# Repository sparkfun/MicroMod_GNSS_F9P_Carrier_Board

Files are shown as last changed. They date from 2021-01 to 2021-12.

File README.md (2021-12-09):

SparkFun MicroMod GNSS Carrier Board (ZED-F9P)
========================================

SparkFun MicroMod GNSS Carrier Board (ZED-F9P) (https://www.sparkfun.com/products/17722)

[*SparkFun MicroMod GNSS Carrier Board (ZED-F9P) (GPS-17722)*](https://www.sparkfun.com/products/17722)

With GNSS you are able to know where you are, where you're going, and how to get there anywhere on Earth within 30 seconds. This means the higher the accuracy the better! GNSS Real Time Kinematics (RTK) has mastered dialing in the accuracy of their GNSS modules to just millimeters, and that's why we had to put it on this board! With the flexibility of the MicroMod's M.2 connector, you can easily test and swap out different MicroMod processor boards for your application. Simply match up the key on your board's beveled edge connector to the key on the M.2 connector and secure the boards with a screw.

The SparkFun MicroMod GNSS Carrier Board raises the bar for high-precision GPS and is in a line of powerful RTK boards featuring the ZED-F9P module from u-blox. The ZED-F9P is a top-of-the-line module for high accuracy GNSS and GPS location solutions including RTK that is capable of 10mm, three-dimensional accuracy. With this board, you will be able to know where your (or any object's) X, Y, and Z location is within roughly the width of your fingernail! The ZED-F9P is unique in that it is capable of both rover and base station operations. Utilizing the M.2 and Qwiic connectors, no soldering is required to connect it to the rest of your system. However, we still broke out 0.1"-spaced pins in case you prefer to use a breadboard to attach additional peripherals.

The board includes two USB-C connectors for power and programming. Two buttons for reset and boot are also populated on the board. A 2A resettable fuse and 3.3V/1A voltage regulator are built-in to the board for power. We've even added a convenient jumper for advanced users looking to bypass the fuse and another to measure the current consumption for low power testing. Five status LEDs are available for power, 3.3V, PPS, RTK, and geofencing. These can also be disabled via the jumper pads. One SMA connector is included for a secure connection to an antenna. For those that need a secure connection to the PPS pin, the SMA connector footprint is included in the design so that you can manually solder it to the board for your application. Finally, one Qwiic connector is populated on the board to easily add Qwiic enabled I<sup>2</sup>C devices to your projects!

We've even included a rechargeable backup battery to keep the latest module configuration and satellite data available for up to two weeks. This battery helps 'warm-start' the module, decreasing the time-to-first-fix dramatically. This module features a survey-in mode allowing the module to become a base station and produce RTCM 3.x correction data.

The number of configuration options of the ZED-F9P is incredible! Geofencing, variable I<sup>2</sup>C address, variable update rates, even the high precision RTK solution can be increased to 20Hz. The MicroMod GNSS carrier board even has five communications ports, four of which are all active simultaneously: USB-C (which enumerates as a COM port), UART1 (with 3.3V TTL), UART2 for RTCM reception (with 3.3V TTL), I<sup>2</sup>C (via the one Qwiic connector or broken out pins), and SPI.

We've also written an extensive [Arduino library for u-blox modules](https://github.com/sparkfun/SparkFun_u-blox_GNSS_Arduino_Library) to make reading and controlling the MicroMod GNSS carrier board over the MicroMod's I<sup>2</sup>C bus is easy. Leave NMEA behind! Start using a much lighter weight binary interface and give your microcontroller (and its one serial port) a break. The SparkFun Arduino library shows how to read latitude, longitude, even heading and speed over I<sup>2</sup>C without the need for constant serial polling.

Repository Contents
-------------------

* **/Hardware** - Eagle design files (.brd, .sch)
* **/Production** - Production panel files (.brd)

Documentation
--------------
* **[Library](https://github.com/sparkfun/SparkFun_u-blox_GNSS_Arduino_Library)** - Arduino library for the u-blox modules (e.g. ZED-F9P)
* **[Hookup Guide](https://learn.sparkfun.com/tutorials/2187)** - Basic hookup guide for the ZED-F9P Carrier Board

Product Versions
----------------
* [GPS-17722](https://www.sparkfun.com/products/17722) 

Version History
---------------
* v1.0 - initial release

License Information
-------------------

This product is _**open source**_! 

Please review the LICENSE.md file for license information. 

If you have any questions or concerns on licensing, please contact technical support on our [SparkFun forums](https://forum.sparkfun.com/viewforum.php?f=152).

Distributed as-is; no warranty is given.

- Your friends at SparkFun.

_<COLLABORATION CREDIT>_

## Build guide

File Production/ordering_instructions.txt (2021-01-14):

panel size, 149x147mm
PCB thickness, 1.6mm
number of layers, 2
soldermask color, Red
silkscreen color, White
oz copper, 1oz
finish, HASL lead free
stencils, top
pcs per panel, 4
min trace width, 0.1524mm / 0.0060in
min drill size, 0.3048mm / 0.0120in

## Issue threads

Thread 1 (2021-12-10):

Voltage divider jumper

adamgarbo, 2021-12-10:
Hi @edspark,

Another exciting design. I assume when I raised the issue regarding the voltage divider jumper with you last that this product was likely already being manufactured?

I know I sound like a broken record by now, but with a couple of small improvements, the power efficiency of the MicroMod ecosystem of products could be vastly improved. I'll keep pushing low power and hopefully one day we'll get there!

Cheers,
Adam

adamgarbo, 2022-03-10:
Power efficiency issues with the MicroMod ecosystem is a known issue and will hopefully be addressed in future MicroMod products.

Closed 2022-03-10.

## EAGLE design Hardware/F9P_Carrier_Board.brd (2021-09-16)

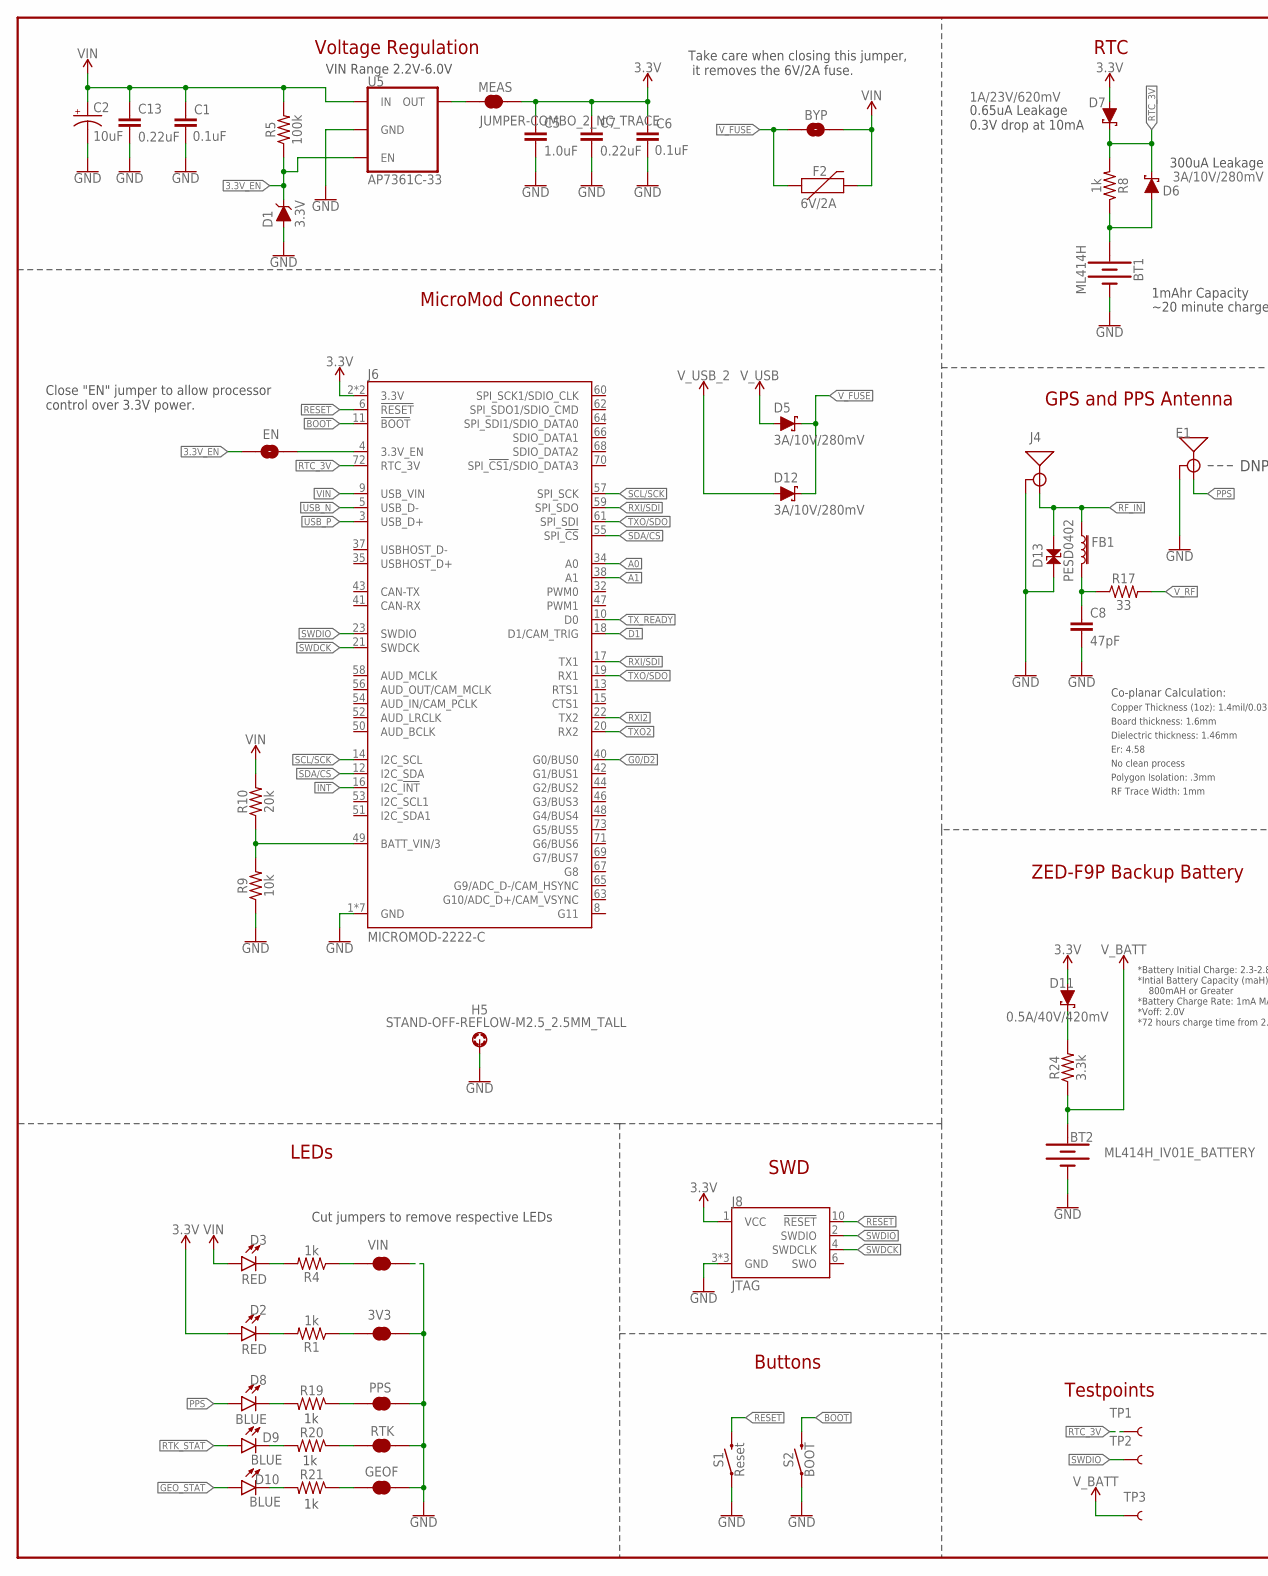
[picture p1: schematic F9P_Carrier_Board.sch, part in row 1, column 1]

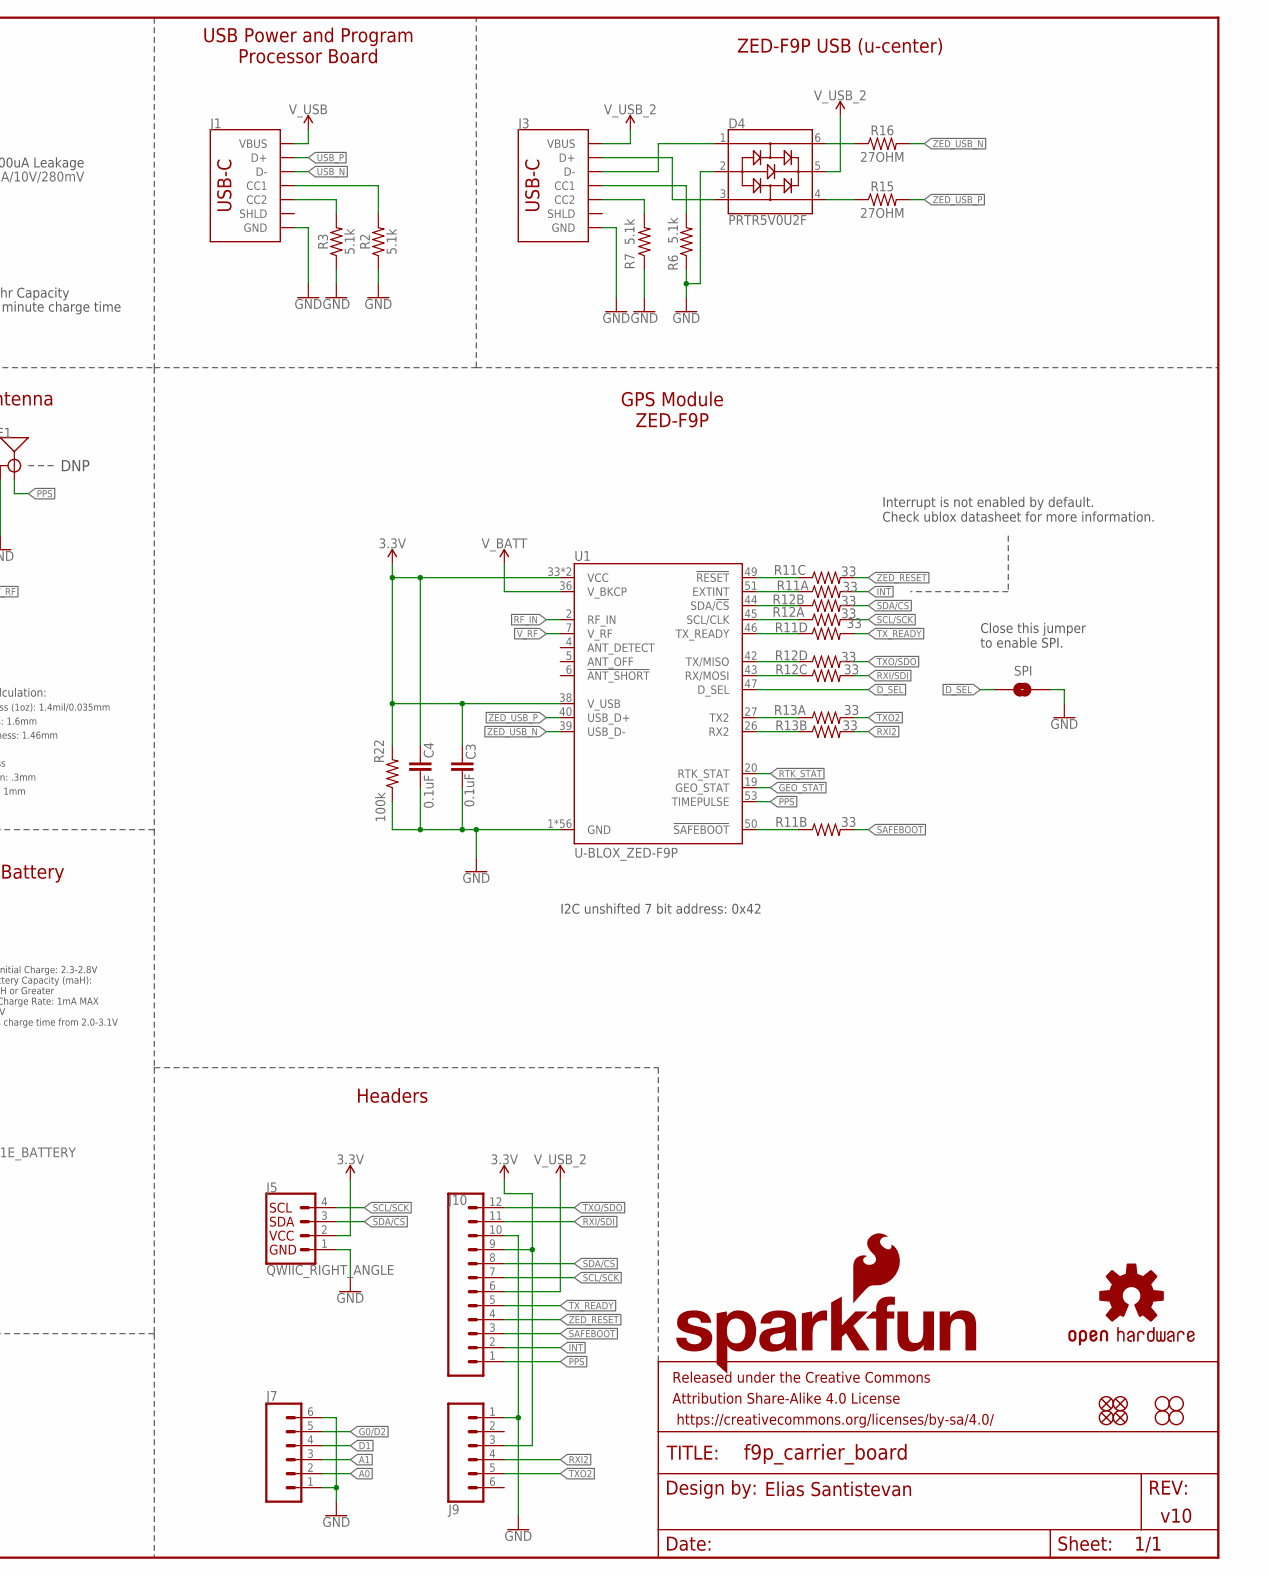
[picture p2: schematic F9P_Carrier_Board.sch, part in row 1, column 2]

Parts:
3V3: JUMPER-SMT_2_NC_TRACE_SILK; SMT-JUMPER_2_NC_TRACE_SILK
BT1: ML414H; ML414H_IV01E
BT2: ML414H_IV01E_BATTERY; ML414H_IV01E
BYP: JUMPER-SMT_2_NO_SILK; SMT-JUMPER_2_NO_SILK
C1, C3, C4, C6: 0.1uF; 0603
C2: 10uF; EIA3216
C5: 1.0uF; 0603
C7, C13: 0.22uF; 0603
C8: 47pF; 0603
D1: 3.3V; SOD-323
D2, D3: RED; LED-0603
D4: PRTR5V0U2F; SOT886
D5, D6, D12: 3A/10V/280mV; SOD-323
D7: 1A/23V/620mV; SOD-323
D8, D9, D10: BLUE; LED-0603
D11: 0.5A/40V/420mV; SOD-323
D13: PESD0402; 0402
E1: ANTENNA-SMA-GROUNDEDEDGE_SMA; SMA-EDGE
EN: JUMPER-SMT_2_NO_SILK; SMT-JUMPER_2_NO_SILK
F2: 6V/2A; 1210
FB1: FERRITE_BEAD-120_OHM-0402T; 0402-TIGHT
FD1, FD2, FD3, FD4: FIDUCIALUFIDUCIAL; FIDUCIAL-MICRO
FRAME1: FRAME-LEDGER; CREATIVE_COMMONS
GEOF: JUMPER-SMT_2_NC_TRACE_SILK; SMT-JUMPER_2_NC_TRACE_SILK
H1, H2, H3, H4: STAND-OFFTIGHT; STAND-OFF-TIGHT
H5: STAND-OFF-REFLOW-M2.5_2.5MM_TALL; STAND-OFF-REFLOW-M2.5
J1, J3: USB_C_2-LAYER_PADS; USB-C-16P-2LAYER-PADS
J4: U.FL; SMA-EDGE
J5: QWIIC_RIGHT_ANGLE; JST04_1MM_RA
J6: MICROMOD-2222-C; M.2-CONNECTOR-E
J7, J9: CONN_06NO_SILK_NO_POP; 1X06_NO_SILK
J8: JTAG; 2X5-PTH-1.27MM
J10: CONN_12NO_SILK; 1X12_NO_SILK
LOGO1: SFE_LOGO_NAME_FLAME.3_INCH; SFE_LOGO_NAME_FLAME_.3
LOGO3: OSHW-LOGOMINI; OSHW-LOGO-MINI
MEAS: JUMPER-COMBO_2_NC_TRACE; COMBO-JUMPER_2_NC_TRACE
PPS: JUMPER-SMT_2_NC_TRACE_SILK; SMT-JUMPER_2_NC_TRACE_SILK
R1, R4, R8, R19, R20, R21: 1k; 0603
R2, R3, R6, R7: 5.1k; 0603
R5, R22: 100k; 0603
R9: 10k; 0603
R10: 20k; 0603
R11, R12, R13: 33; 1206_RA
R15, R16: 27OHM; 0402-TIGHT
R17: 33; 0603
R24: 3.3k; 0603
RTK: JUMPER-SMT_2_NC_TRACE_SILK; SMT-JUMPER_2_NC_TRACE_SILK
S1: Reset; TACTILE_SWITCH_SMD_5.2MM
S2: BOOT; TACTILE_SWITCH_SMD_5.2MM
SPI: JUMPER-SMT_2_NO_SILK; SMT-JUMPER_2_NO_SILK
TP1, TP2, TP3: TEST-POINT3X5; PAD.03X.05
U1: U-BLOX_ZED-F9P; ZED-F9P
U5: AP7361C-33; UDFN-8
VIN: JUMPER-SMT_2_NC_TRACE_SILK; SMT-JUMPER_2_NC_TRACE_SILK

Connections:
3.3V: C3.1, C4.1, C5.1, C6.1, C7.1, D2.A, D7.A, D11.A, J5.2, J6.2 (3.3V), J6.74 (3.3V), J8.1 (VCC), J9.3, J10.9, MEAS.2, MEAS.4 (2), R22.2, U1.33 (VCC), U1.34 (VCC), U1.38 (V_USB)
3.3V_EN: D1.C, EN.1, R5.1, U5.5 (EN)
!BOOT!: J6.11 (!BOOT!), S2.3 (2), S2.4 (2)
!RESET!: J6.6 (!RESET!), J8.10 (!RESET), S1.3 (2), S1.4 (2)
!SAFEBOOT!: J10.3, R11.P7 (2)
!ZED_RESET!: J10.4, R11.P6 (2)
A0: J6.34 (A0), J7.2
A1: J6.38 (A1), J7.3
D1: J6.18 (D1/CAM_TRIG), J7.4
D_SEL: SPI.1, U1.47 (D_SEL)
G0/D2: J6.40 (G0/BUS0), J7.5
GEO_STAT: D10.A, U1.19 (GEO_STAT)
GND: 3V3.2, BT1.-, BT2.-, C1.2, C2.-, C3.2, C4.2, C5.2, C6.2, C7.2, C8.2, C13.2, D1.A, D4.2, D13.1, E1.GND@0 (GND), E1.GND@1 (GND), E1.GND@2 (GND), E1.GND@3 (GND), GEOF.1, H5.1, J1.GND, J1.GND2 (GND), J3.GND, J3.GND2 (GND), J4.GND@0 (GND), J4.GND@1 (GND), J4.GND@2 (GND), J4.GND@3 (GND), J5.1, J6.1 (GND), J6.7 (GND), J6.33 (GND), J6.36 (GND), J6.39 (GND), J6.45 (GND), J6.75 (GND), J7.1, J7.6, J8.3 (GND), J8.5 (GND), J8.9 (GND), J9.1, J10.10, PPS.1, R2.1, R3.1, R6.1, R7.1, R9.1, R22.1, RTK.1, S1.1, S1.2 (1), S2.1, S2.2 (1), SPI.2, U1.1 (GND), U1.3 (GND), U1.12 (GND), U1.14 (GND), U1.32 (GND), U1.37 (GND), U1.41 (GND), U1.48 (GND), U1.55 (GND), U1.56 (GND), U1.57 (GND), U1.58 (GND), U1.59 (GND), U1.60 (GND), U1.61 (GND), U1.62 (GND), U1.63 (GND), U1.64 (GND), U1.65 (GND), U1.66 (GND), U1.67 (GND), U1.68 (GND), U1.69 (GND), U1.70 (GND), U1.71 (GND), U1.72 (GND), U1.73 (GND), U1.74 (GND), U1.75 (GND), U1.76 (GND), U1.77 (GND), U1.78 (GND), U1.79 (GND), U1.80 (GND), U1.81 (GND), U1.82 (GND), U1.83 (GND), U1.84 (GND), U1.85 (GND), U1.86 (GND), U1.87 (GND), U1.88 (GND), U1.89 (GND), U1.90 (GND), U1.91 (GND), U1.92 (GND), U1.93 (GND), U1.94 (GND), U1.95 (GND), U1.96 (GND), U1.97 (GND), U1.98 (GND), U1.99 (GND), U1.100 (GND), U1.101 (GND), U1.102 (GND), U5.4 (GND), U5.EP (GND), VIN.2
INT: J6.16 (I2C_!INT!), J10.2, R11.P8 (2)
unnamed: D2.C, R1.2
unnamed: R4.1, VIN.1
unnamed: 3V3.1, R1.1
unnamed: D3.C, R4.2
unnamed: EN.2, J6.4 (3.3V_EN)
unnamed: J3.A5 (CC1), R6.2
unnamed: J3.B5 (CC2), R7.2
unnamed: R20.1, RTK.2
unnamed: D4.6, R16.1
unnamed: J1.A5 (CC1), R2.2
unnamed: J1.B5 (CC2), R3.2
unnamed: D4.3, J3.A6 (D+), J3.B6 (D+)
unnamed: D4.1, J3.A7 (D-), J3.B7 (D-)
unnamed: BT1.+, D6.A, R8.1
unnamed: R11.P1 (1), U1.51 (EXTINT)
unnamed: R11.P2 (1), U1.50 (!SAFEBOOT!)
unnamed: D4.4, R15.1
unnamed: C8.1, FB1.2, R17.1
unnamed: R11.P3 (1), U1.49 (!RESET!)
unnamed: R11.P4 (1), U1.46 (TX_READY)
unnamed: R12.P1 (1), U1.45 (SCL/CLK)
unnamed: R12.P2 (1), U1.44 (SDA/!CS!)
unnamed: R12.P3 (1), U1.43 (RX/MOSI)
unnamed: R12.P4 (1), U1.42 (TX/MISO)
unnamed: R13.P1 (1), U1.27 (TX2)
unnamed: R13.P2 (1), U1.26 (RX2)
unnamed: PPS.2, R19.1
unnamed: D8.C, R19.2
unnamed: D9.C, R20.2
unnamed: D11.C, R24.2
unnamed: GEOF.2, R21.1
unnamed: D10.C, R21.2
OUT_MEAS: MEAS.1, MEAS.3 (1), U5.1 (OUT)
PPS: D8.A, E1.SIG (SIGNAL), J10.1, U1.53 (TIMEPULSE)
RF_IN: D13.2, FB1.1, J4.SIG (SIGNAL), U1.2 (RF_IN)
RTC_3V: D6.C, D7.C, J6.72 (RTC_3V), R8.2, TP1.1
RTK_STAT: D9.A, U1.20 (RTK_STAT)
RXI2: J6.22 (TX2), J9.4, R13.P7 (2)
RXI/SDI: J6.17 (TX1), J6.59 (SPI_SDO), J10.11, R12.P6 (2)
SCL/SCK: J5.4, J6.14 (I2C_SCL), J6.57 (SPI_SCK), J10.7, R12.P8 (2)
SDA/!CS!: J5.3, J6.12 (I2C_SDA), J6.55 (SPI_!CS!), J10.8, R12.P7 (2)
SWDCK: J6.21 (SWDCK), J8.4 (SWDCLK)
SWDIO: J6.23 (SWDIO), J8.2 (SWDIO), TP2.1
TXO2: J6.20 (RX2), J9.5, R13.P8 (2)
TXO/SDO: J6.19 (RX1), J6.61 (SPI_SDI), J10.12, R12.P5 (2)
TX_READY: J6.10 (D0), J10.5, R11.P5 (2)
USB_N: J1.A7 (D-), J1.B7 (D-), J6.5 (USB_D-)
USB_P: J1.A6 (D+), J1.B6 (D+), J6.3 (USB_D+)
VIN: BYP.2, C1.1, C2.+, C13.1, D3.A, F2.2, J6.9 (USB_VIN), R5.2, R10.2, U5.8 (IN)
VIN/3: J6.49 (BATT_VIN/3), R9.2, R10.1
V_BATT: BT2.+, R24.1, TP3.1, U1.36 (V_BKCP)
V_FUSE: BYP.1, D5.C, D12.C, F2.1
V_RF: R17.2, U1.7 (V_RF)
V_USB: D5.A, J1.VBUS1 (VBUS), J1.VBUS2 (VBUS)
V_USB_2: D4.5, D12.A, J3.VBUS1 (VBUS), J3.VBUS2 (VBUS), J10.6
ZED_USB_N: R16.2, U1.39 (USB_D-)
ZED_USB_P: R15.2, U1.40 (USB_D+)

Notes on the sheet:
300uA Leakage
0.65uA Leakage 0.3V drop at 10mA
~20 minute charge time
1mAhr Capacity
Take care when closing this jumper, it removes the 6V/2A fuse.
RTC
Voltage Regulation
MicroMod Connector
Elias Santistevan
LEDs
Buttons
VIN Range 2.2V-6.0V
Testpoints
*Battery Initial Charge: 2.3-2.8V *Intial Battery Capacity (maH): 800mAH or Greater *Battery Charge Rate: 1mA MAX *Voff: 2.0V *72 hours charge time from 2.0-3.1V
ZED-F9P Backup Battery
Headers
ZED-F9P USB (u-center)
USB Power and Program Processor Board
v10
GPS and PPS Antenna
GPS Module ZED-F9P
SWD
Board thickness: 1.6mm
Er: 4.58
Copper Thickness (1oz): 1.4mil/0.035mm
RF Trace Width: 1mm
Polygon Isolation: .3mm
No clean process
Dielectric thickness: 1.46mm
Co-planar Calculation:
DNP
Close this jumper to enable SPI.
Cut jumpers to remove respective LEDs
Close "EN" jumper to allow processor control over 3.3V power.
Interrupt is not enabled by default. Check ublox datasheet for more information.
I2C unshifted 7 bit address: 0x42

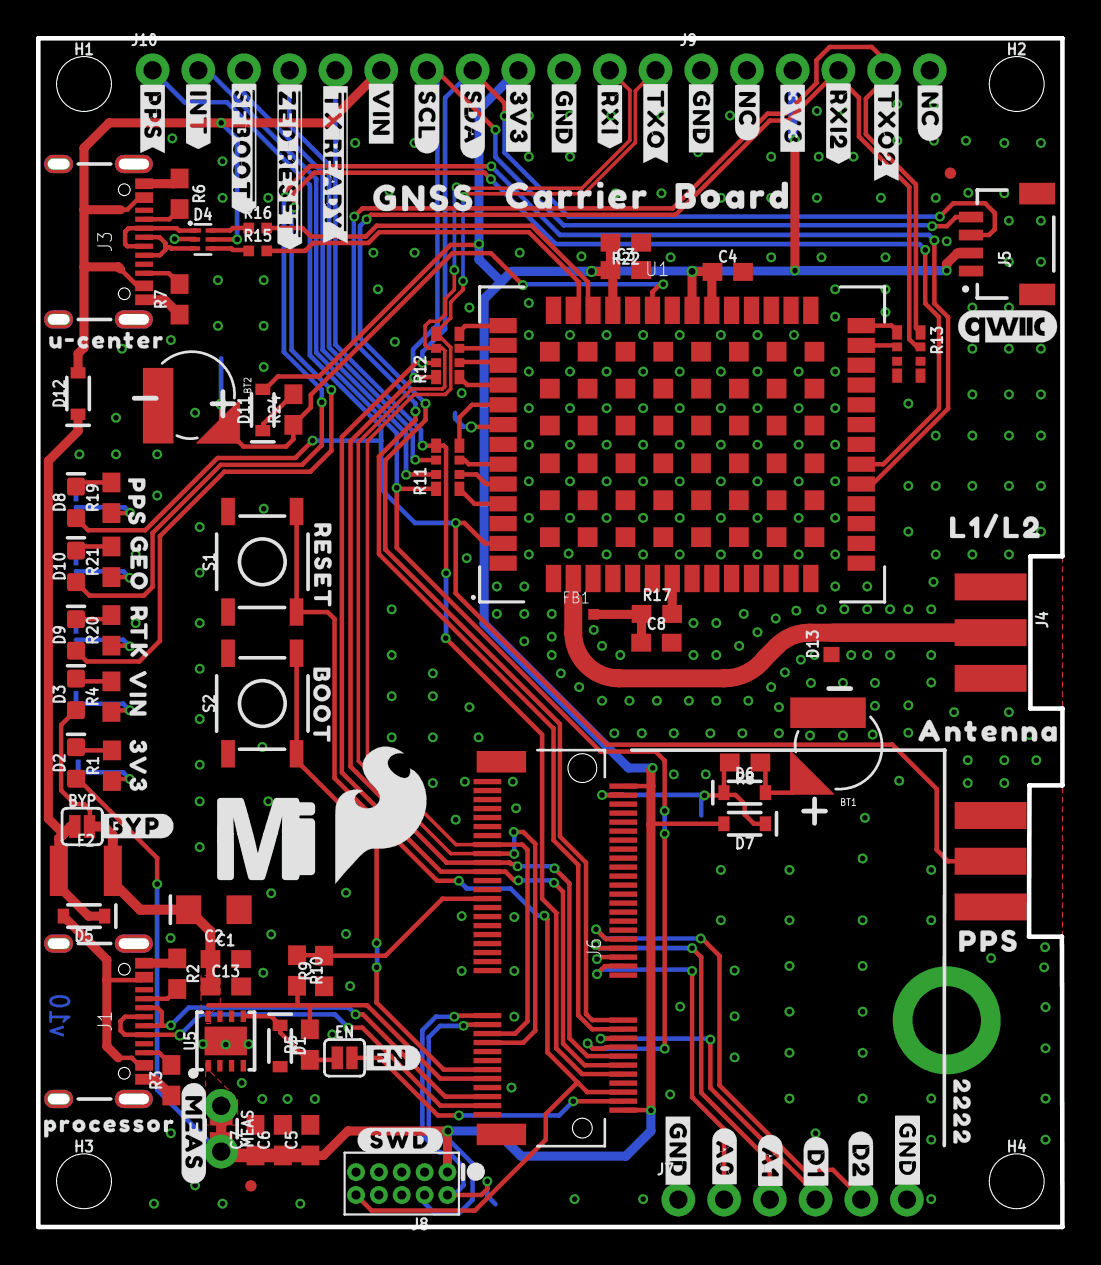
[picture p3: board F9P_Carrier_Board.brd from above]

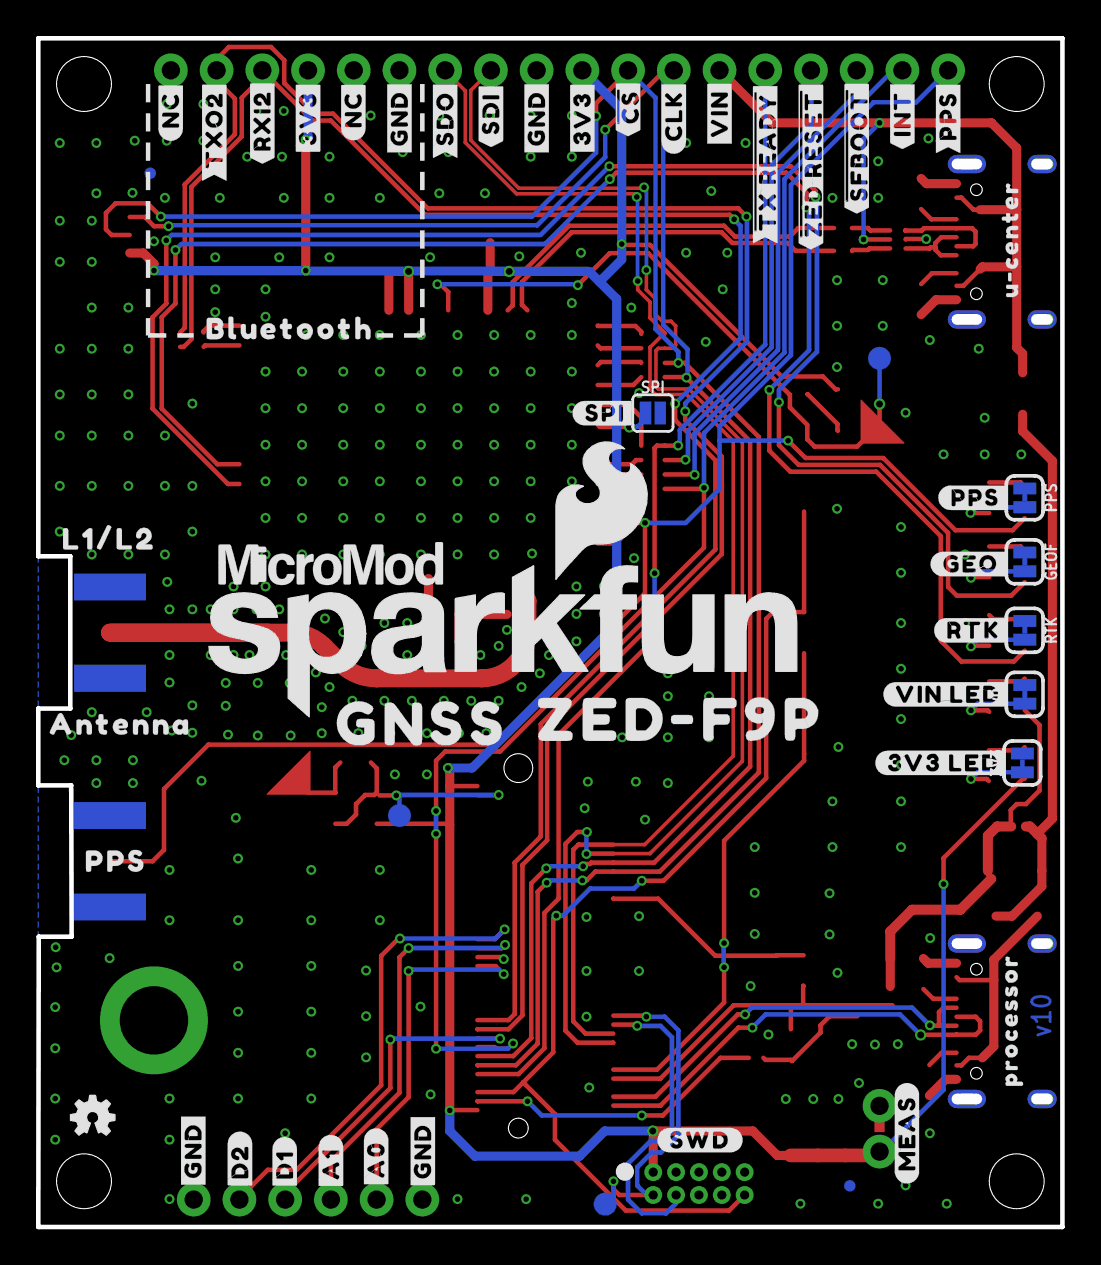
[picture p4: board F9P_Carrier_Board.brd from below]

Board: 2 copper layers, 56.9 x 66.0 mm, 174 parts (54 on the bottom side), 71 nets.

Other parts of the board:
U$1: ##SFBOOT##13
U$2: ##SFBOOT##8
U$3, U$4, U$31, U$32: #3V3#1
U$5: #RESET10
U$6, U$7, U$33, U$34, U$64, U$65, U$66, U$77, U$78: #GND#0
U$8: ##TX_READY##13
U$9: #PPS#6
U$10: #SCL#1
U$11: #RXI2#9
U$12: #SDA#0
U$13: #TXO#5
U$14: #RXI#6
U$15: #TXO2#9
U$16: PPS15
U$17, U$35: #VIN#13
U$18: GEO15
U$19: PPS14
U$20: RTK16
U$21: ANTENNA16
U$22: L1#L216
U$23: #GEO#9
U$24: ##TX_READY##7
U$25: MICROMOD_LOGO_.5
U$26: #PPS#10
U$27: #RTK#8
U$28: ##CS##9
U$29: #INT#4
U$30: #SPI#11
U$36: #INT#10
U$37: #PPS#3
U$38: #TXO2#10
U$39: #BYP#8
U$40: #RXI2#10
U$41: MICROMOD_MI_LOGO_1
U$42, U$132: #MEAS#10
U$43: BOOT10
U$44: ZED#F9P19
U$45: GNSS21
U$46: #CLK#7
U$47: #SDO#9
U$48: #EN#0
U$49: U#CENTER20
U$50: QWIIC_5.5MM
U$51, U$131: #SWD#10
U$52, U$73: PROCESSOR23
U$53: #SDI#11
U$54: BLUETOOTH24
U$55, U$83: #NC#4
U$56: U#CENTER22
U$57: #A0#14
U$58: L1#L217
U$59: ANTENNA17
U$60: PPS16
U$61: ##ZED_RESET##9
U$62: ##ZED_RESET##14
U$63: SFE_LOGO_FLAME_.3
U$67: #A0#8
U$68: VIN3
U$69: 3V34
U$70: #A1#8
U$71: #D1#8
U$72: #D2#8
U$74: #A1#14
U$75: #D1#14
U$76: #D2#14
U$79: GNSS501
U$80: CARRIER502
U$81: BOARD503
U$82: 2222501
U$84, U$85: #NC#5
U$133: #VIN_LED#10
U$134: #3V3_LED#10

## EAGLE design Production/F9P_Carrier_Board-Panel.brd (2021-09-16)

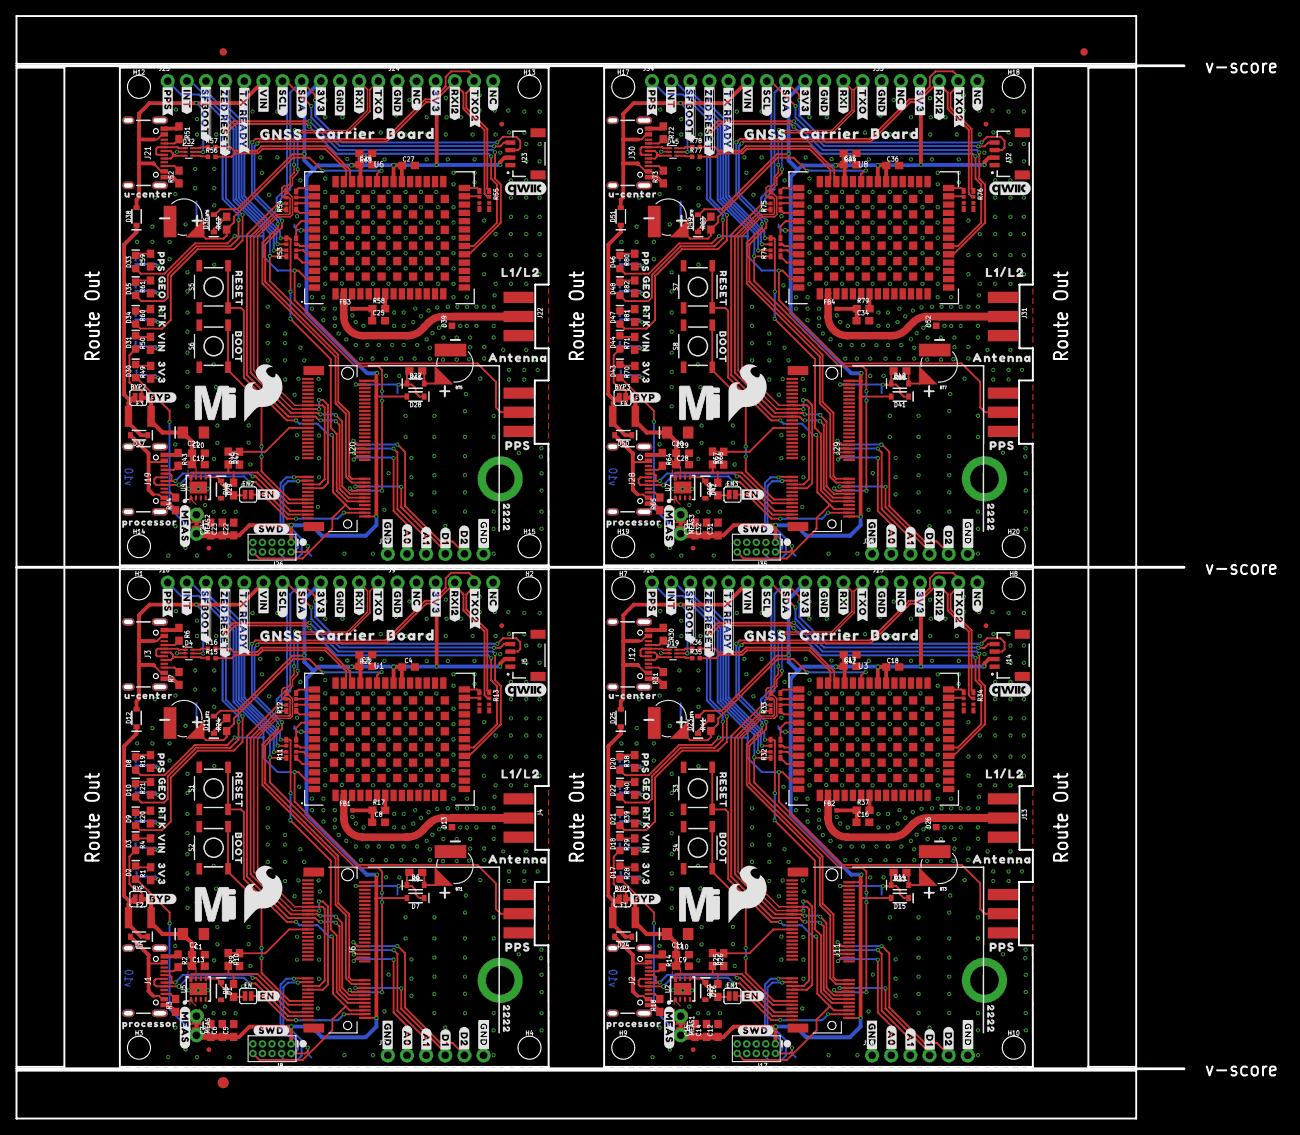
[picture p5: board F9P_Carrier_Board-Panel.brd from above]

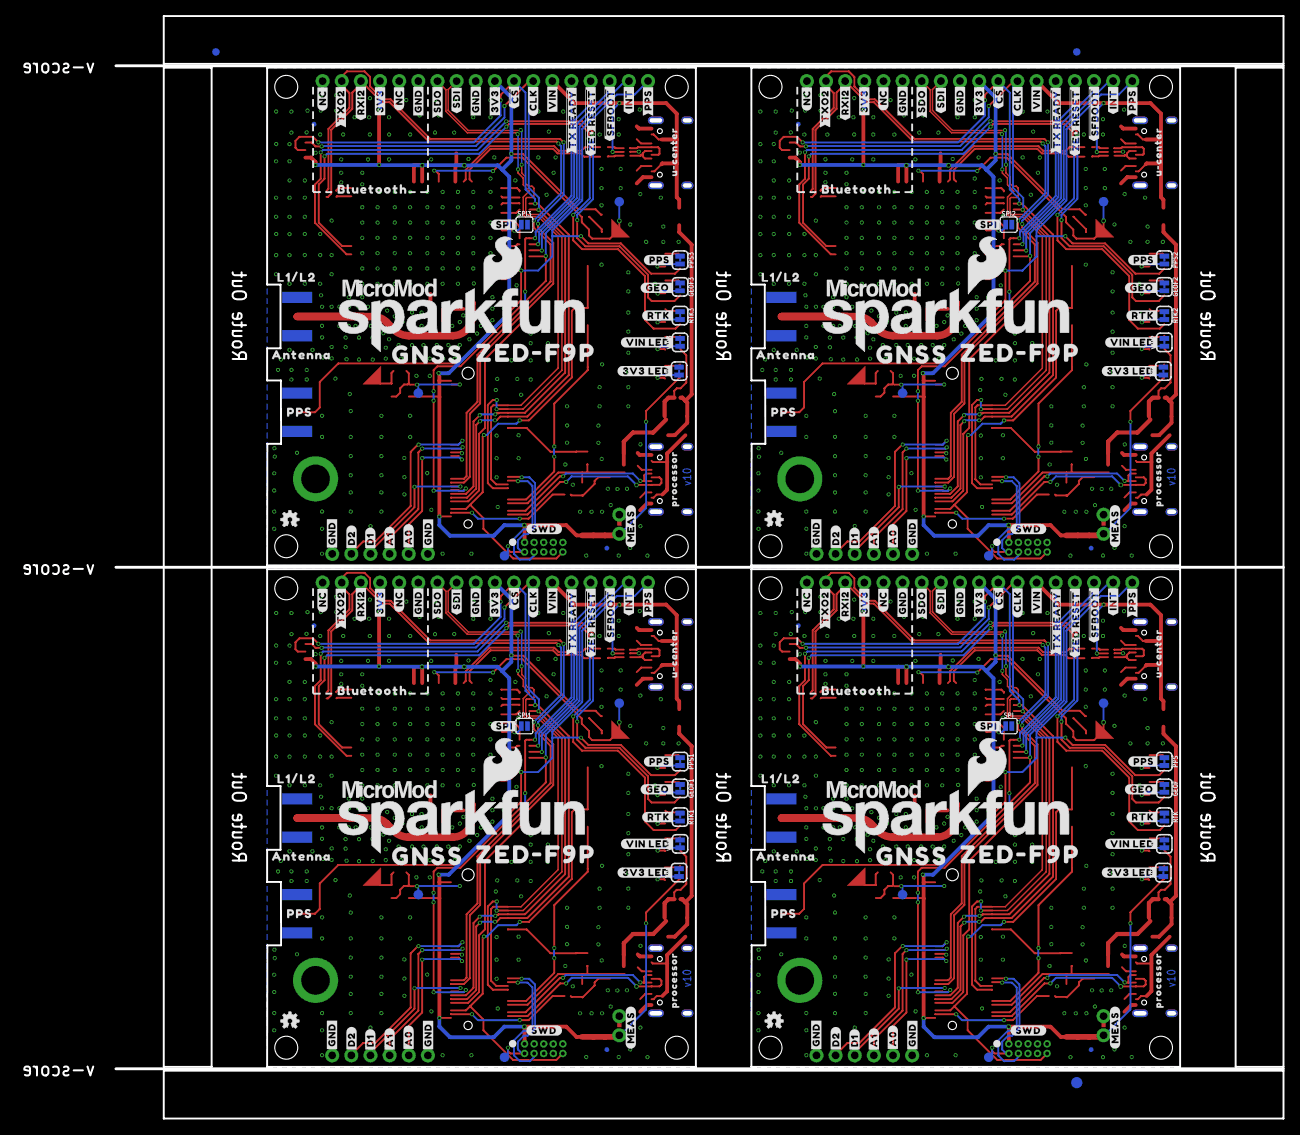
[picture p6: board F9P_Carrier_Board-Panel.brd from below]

Board: 2 copper layers, 154.9 x 146.3 mm, 698 parts (219 on the bottom side), 284 nets.

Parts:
3V1, 3V2, 3V3, 3V4: JUMPER-SMT_2_NC_TRACE_SILK; SMT-JUMPER_2_NC_TRACE_SILK
BT1, BT3, BT5, BT7: ML414H; ML414H_IV01E
BT2, BT4, BT6, BT8: ML414H_IV01E_BATTERY; ML414H_IV01E
BYP, BYP1, BYP2, BYP3: JUMPER-SMT_2_NO_SILK; SMT-JUMPER_2_NO_SILK
C1, C3, C4, C6, C10, C14, C17, C18, C20, C23, C26, C27, C29, C32, C35, C36: 0.1uF; 0603
C2, C11, C21, C30: 10uF; EIA3216
C5, C12, C22, C31: 1.0uF; 0603
C7, C9, C13, C15, C19, C24, C28, C33: 0.22uF; 0603
C8, C16, C25, C34: 47pF; 0603
D1, D16, D29, D42: 3.3V; SOD-323
D2, D3, D17, D18, D30, D31, D43, D44: RED; LED-0603
D4, D19, D32, D45: PRTR5V0U2F; SOT886
D5, D6, D12, D14, D24, D25, D27, D37, D38, D40, D50, D51: 3A/10V/280mV; SOD-323
D7, D15, D28, D41: 1A/23V/620mV; SOD-323
D8, D9, D10, D20, D21, D22, D33, D34, D35, D46, D47, D48: BLUE; LED-0603
D11, D23, D36, D49: 0.5A/40V/420mV; SOD-323
D13, D26, D39, D52: PESD0402; 0402
E1, E2, E3, E4: ANTENNA-SMA-GROUNDEDEDGE_SMA; SMA-EDGE
E$1, E$2, E$3, E$4: FIDUCIAL-1X2
E$5, E$6: FIDUCIAL-1.5X3
EN, EN1, EN2, EN3: JUMPER-SMT_2_NO_SILK; SMT-JUMPER_2_NO_SILK
F1, F2, F3, F4: 6V/2A; 1210
FB1, FB2, FB3, FB4: FERRITE_BEAD-120_OHM-0402T; 0402-TIGHT
FD1, FD2, FD3, FD4, FD5, FD6, FD7, FD8, FD9, FD10, FD11, FD12, FD13, FD14, FD15, FD16: FIDUCIALUFIDUCIAL; FIDUCIAL-MICRO
GEOF, GEOF1, GEOF2, GEOF3: JUMPER-SMT_2_NC_TRACE_SILK; SMT-JUMPER_2_NC_TRACE_SILK
H1, H2, H3, H4, H7, H8, H9, H10, H12, H13, H14, H15, H17, H18, H19, H20: STAND-OFFTIGHT; STAND-OFF-TIGHT
H5, H6, H11, H16: STAND-OFF-REFLOW-M2.5_2.5MM_TALL; STAND-OFF-REFLOW-M2.5
J1, J2, J3, J12, J19, J21, J28, J30: USB-C-16P-2LAYER-PADS
J4, J13, J22, J31: U.FL; SMA-EDGE
J5, J14, J23, J32: QWIIC_RIGHT_ANGLE; JST04_1MM_RA
J6, J11, J20, J29: MICROMOD-2222-C; M.2-CONNECTOR-E
J7, J9, J15, J18, J24, J27, J33, J36: 1X06_NO_SILK
J8, J17, J26, J35: JTAG; 2X5-PTH-1.27MM
J10, J16, J25, J34: 1X12_NO_SILK
LOGO1, LOGO4, LOGO6, LOGO8: SFE_LOGO_NAME_FLAME.3_INCH; SFE_LOGO_NAME_FLAME_.3
LOGO2, LOGO3, LOGO5, LOGO7: OSHW-LOGOMINI; OSHW-LOGO-MINI
MEAS, MEAS1, MEAS2, MEAS3: JUMPER-COMBO_2_NC_TRACE; COMBO-JUMPER_2_NC_TRACE
PPS, PPS1, PPS2, PPS3: JUMPER-SMT_2_NC_TRACE_SILK; SMT-JUMPER_2_NC_TRACE_SILK
R1, R4, R8, R19, R20, R21, R23, R28, R29, R38, R39, R40, R45, R49, R50, R59, R60, R61, R66, R70, R71, R80, R81, R82: 1k; 0603
R2, R3, R6, R7, R14, R18, R30, R31, R43, R44, R51, R52, R64, R65, R72, R73: 5.1k; 0603
R5, R22, R27, R42, R48, R63, R69, R84: 100k; 0603
R9, R25, R46, R67: 10k; 0603
R10, R26, R47, R68: 20k; 0603
R11, R12, R13, R32, R33, R34, R53, R54, R55, R74, R75, R76: 33; 1206_RA
R15, R16, R35, R36, R56, R57, R77, R78: 27OHM; 0402-TIGHT
R17, R37, R58, R79: 33; 0603
R24, R41, R62, R83: 3.3k; 0603
RTK, RTK1, RTK2, RTK3: JUMPER-SMT_2_NC_TRACE_SILK; SMT-JUMPER_2_NC_TRACE_SILK
S1, S3, S5, S7: Reset; TACTILE_SWITCH_SMD_5.2MM
S2, S4, S6, S8: BOOT; TACTILE_SWITCH_SMD_5.2MM
SPI, SPI1, SPI2, SPI3: JUMPER-SMT_2_NO_SILK; SMT-JUMPER_2_NO_SILK
TP1, TP2, TP3, TP4, TP5, TP6, TP7, TP8, TP9, TP10, TP11, TP12: TEST-POINT3X5; PAD.03X.05
U1, U3, U6, U8: U-BLOX_ZED-F9P; ZED-F9P
U2, U4, U5, U7: AP7361C-33; UDFN-8
U$1, U$150, U$239, U$328: ##SFBOOT##13
U$2, U$151, U$240, U$329: ##SFBOOT##8
U$3, U$4, U$31, U$32, U$98, U$99, U$113, U$114, U$191, U$192, U$206, U$207, U$280, U$281, U$295, U$296: #3V3#1
U$5, U$87, U$180, U$269: #RESET10
U$6, U$7, U$33, U$34, U$64, U$65, U$66, U$77, U$78, U$100, U$101, U$115, U$116, U$155, U$156, U$157, U$168, U$169, U$193, U$194, U$208, U$209, U$244, U$245, U$246, U$257, U$258, U$282, U$283, U$297, U$298, U$333, U$334, U$335, U$346, U$347: #GND#0
U$8, U$119, U$212, U$301: ##TX_READY##13
U$9, U$102, U$195, U$284: #PPS#6
U$10, U$128, U$221, U$310: #SCL#1
U$11, U$103, U$196, U$285: #RXI2#9
U$12, U$129, U$222, U$311: #SDA#0
U$13, U$130, U$223, U$312: #TXO#5
U$14, U$135, U$224, U$313: #RXI#6
U$15, U$104, U$197, U$286: #TXO2#9
U$16, U$136, U$225, U$314: PPS15
U$17, U$35, U$105, U$117, U$198, U$210, U$287, U$299: #VIN#13
U$18, U$106, U$199, U$288: GEO15
U$19, U$107, U$200, U$289: PPS14
U$20, U$108, U$201, U$290: RTK16
U$21, U$137, U$226, U$315: ANTENNA16
U$22, U$138, U$227, U$316: L1#L216
U$23, U$109, U$202, U$291: #GEO#9
U$24, U$120, U$213, U$302: ##TX_READY##7
U$25, U$152, U$241, U$330: MICROMOD_LOGO_.5
U$26, U$110, U$203, U$292: #PPS#10
U$27, U$111, U$204, U$293: #RTK#8
U$28, U$139, U$228, U$317: ##CS##9
U$29, U$121, U$214, U$303: #INT#4
U$30, U$112, U$205, U$294: #SPI#11
U$36, U$118, U$211, U$300: #INT#10
U$37, U$122, U$215, U$304: #PPS#3
U$38, U$123, U$216, U$305: #TXO2#10
U$39, U$86, U$179, U$268: #BYP#8
U$40, U$124, U$217, U$306: #RXI2#10
U$41, U$153, U$242, U$331: MICROMOD_MI_LOGO_1
U$42, U$89, U$94, U$132, U$182, U$187, U$271, U$276: #MEAS#10
U$43, U$88, U$181, U$270: BOOT10
U$44, U$125, U$218, U$307: ZED#F9P19
U$45, U$170, U$259, U$348: GNSS21
U$46, U$140, U$229, U$318: #CLK#7
U$47, U$141, U$230, U$319: #SDO#9
U$48, U$97, U$190, U$279: #EN#0
U$49, U$126, U$219, U$308: U#CENTER20
U$50, U$127, U$220, U$309: QWIIC_5.5MM
U$51, U$90, U$93, U$131, U$183, U$186, U$272, U$275: #SWD#10
U$52, U$73, U$162, U$163, U$251, U$252, U$340, U$341: PROCESSOR23
U$53, U$142, U$231, U$320: #SDI#11
U$54, U$143, U$232, U$321: BLUETOOTH24
U$55, U$83, U$175, U$176, U$264, U$265, U$353, U$354: #NC#4
U$56, U$144, U$233, U$322: U#CENTER22
U$57, U$164, U$253, U$342: #A0#14
U$58, U$145, U$234, U$323: L1#L217
U$59, U$146, U$235, U$324: ANTENNA17
U$60, U$147, U$236, U$325: PPS16
U$61, U$148, U$237, U$326: ##ZED_RESET##9
U$62, U$149, U$238, U$327: ##ZED_RESET##14
U$63, U$154, U$243, U$332: SFE_LOGO_FLAME_.3
U$67, U$158, U$247, U$336: #A0#8
U$68, U$91, U$184, U$273: VIN3
U$69, U$92, U$185, U$274: 3V34
U$70, U$159, U$248, U$337: #A1#8
U$71, U$160, U$249, U$338: #D1#8
U$72, U$161, U$250, U$339: #D2#8
U$74, U$165, U$254, U$343: #A1#14
U$75, U$166, U$255, U$344: #D1#14
U$76, U$167, U$256, U$345: #D2#14
U$79, U$171, U$260, U$349: GNSS501
U$80, U$172, U$261, U$350: CARRIER502
U$81, U$173, U$262, U$351: BOARD503
U$82, U$174, U$263, U$352: 2222501
U$84, U$85, U$177, U$178, U$266, U$267, U$355, U$356: #NC#5
U$95, U$133, U$188, U$277: #VIN_LED#10
U$96, U$134, U$189, U$278: #3V3_LED#10
VIN, VIN1, VIN2, VIN3: JUMPER-SMT_2_NC_TRACE_SILK; SMT-JUMPER_2_NC_TRACE_SILK

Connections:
3.3V: C3.1, C4.1, C5.1, C6.1, C7.1, D2.A, D7.A, D11.A, J5.2, J6.2, J6.74, J8.1, J9.3, J10.9, MEAS.2, MEAS.4, R22.2, U1.33, U1.34, U1.38
3.3V1: C12.1, C14.1, C15.1, C17.1, C18.1, D15.A, D17.A, D23.A, J11.2, J11.74, J14.2, J15.3, J16.9, J17.1, MEAS1.2, MEAS1.4, R42.2, U3.33, U3.34, U3.38
3.3V2: C22.1, C23.1, C24.1, C26.1, C27.1, D28.A, D30.A, D36.A, J20.2, J20.74, J23.2, J24.3, J25.9, J26.1, MEAS2.2, MEAS2.4, R63.2, U6.33, U6.34, U6.38
3.3V3: C31.1, C32.1, C33.1, C35.1, C36.1, D41.A, D43.A, D49.A, J29.2, J29.74, J32.2, J33.3, J34.9, J35.1, MEAS3.2, MEAS3.4, R84.2, U8.33, U8.34, U8.38
3.3V_EN: D1.C, EN.1, R5.1, U5.5
3.3V_EN1: D16.C, EN1.1, R27.1, U2.5
3.3V_EN2: D29.C, EN2.1, R48.1, U4.5
3.3V_EN3: D42.C, EN3.1, R69.1, U7.5
!BOOT!: J6.11, S2.3, S2.4
!BOOT!1: J11.11, S4.3, S4.4
!BOOT!2: J20.11, S6.3, S6.4
!BOOT!3: J29.11, S8.3, S8.4
!RESET!: J6.6, J8.10, S1.3, S1.4
!RESET!1: J11.6, J17.10, S3.3, S3.4
!RESET!2: J20.6, J26.10, S5.3, S5.4
!RESET!3: J29.6, J35.10, S7.3, S7.4
!SAFEBOOT!: J10.3, R11.P7
!SAFEBOOT!1: J16.3, R32.P7
!SAFEBOOT!2: J25.3, R53.P7
!SAFEBOOT!3: J34.3, R74.P7
!ZED_RESET!: J10.4, R11.P6
!ZED_RESET!1: J16.4, R32.P6
!ZED_RESET!2: J25.4, R53.P6
!ZED_RESET!3: J34.4, R74.P6
A0: J6.34, J7.2
A1: J6.38, J7.3
A2: J11.38, J18.3
A3: J11.34, J18.2
A4: J20.38, J27.3
A5: J20.34, J27.2
A6: J29.38, J36.3
A7: J29.34, J36.2
D1: J6.18, J7.4
D2: J11.18, J18.4
D3: J20.18, J27.4
D4: J29.18, J36.4
D_SEL: SPI.1, U1.47
D_SEL1: SPI1.1, U3.47
D_SEL2: SPI2.1, U6.47
D_SEL3: SPI3.1, U8.47
G0/D1: J11.40, J18.5
G0/D2: J6.40, J7.5
G0/D3: J20.40, J27.5
G0/D4: J29.40, J36.5
GEO_STAT: D10.A, U1.19
GEO_STAT1: D22.A, U3.19
GEO_STAT2: D35.A, U6.19
GEO_STAT3: D48.A, U8.19
GND: 3V3.2, BT1.-, BT2.-, C1.2, C2.-, C3.2, C4.2, C5.2, C6.2, C7.2, C8.2, C13.2, D1.A, D4.2, D13.1, E1.GND@0, E1.GND@1, E1.GND@2, E1.GND@3, GEOF.1, H5.1, J1.GND, J1.GND2, J3.GND, J3.GND2, J4.GND@0, J4.GND@1, J4.GND@2, J4.GND@3, J5.1, J6.1, J6.7, J6.33, J6.36, J6.39, J6.45, J6.75, J7.1, J7.6, J8.3, J8.5, J8.9, J9.1, J10.10, PPS.1, R2.1, R3.1, R6.1, R7.1, R9.1, R22.1, RTK.1, S1.1, S1.2, S2.1, S2.2, SPI.2, U1.1, U1.3, U1.12, U1.14, U1.32, U1.37, U1.41, U1.48, U1.55, U1.56, U1.57, U1.58, U1.59, U1.60, U1.61, U1.62, U1.63, U1.64, U1.65, U1.66, U1.67, U1.68, U1.69, U1.70, U1.71, U1.72, U1.73, U1.74, U1.75, U1.76, U1.77, U1.78, U1.79, U1.80, U1.81, U1.82, U1.83, U1.84, U1.85, U1.86, U1.87, U1.88, U1.89, U1.90, U1.91, U1.92, U1.93, U1.94, U1.95, U1.96, U1.97, U1.98, U1.99, U1.100, U1.101, U1.102, U5.4, U5.EP, VIN.2
GND1: 3V1.2, BT3.-, BT4.-, C9.2, C10.2, C11.-, C12.2, C14.2, C15.2, C16.2, C17.2, C18.2, D16.A, D19.2, D26.1, E2.GND@0, E2.GND@1, E2.GND@2, E2.GND@3, GEOF1.1, H6.1, J2.GND, J2.GND2, J11.1, J11.7, J11.33, J11.36, J11.39, J11.45, J11.75, J12.GND, J12.GND2, J13.GND@0, J13.GND@1, J13.GND@2, J13.GND@3, J14.1, J15.1, J16.10, J17.3, J17.5, J17.9, J18.1, J18.6, PPS1.1, R14.1, R18.1, R25.1, R30.1, R31.1, R42.1, RTK1.1, S3.1, S3.2, S4.1, S4.2, SPI1.2, U2.4, U2.EP, U3.1, U3.3, U3.12, U3.14, U3.32, U3.37, U3.41, U3.48, U3.55, U3.56, U3.57, U3.58, U3.59, U3.60, U3.61, U3.62, U3.63, U3.64, U3.65, U3.66, U3.67, U3.68, U3.69, U3.70, U3.71, U3.72, U3.73, U3.74, U3.75, U3.76, U3.77, U3.78, U3.79, U3.80, U3.81, U3.82, U3.83, U3.84, U3.85, U3.86, U3.87, U3.88, U3.89, U3.90, U3.91, U3.92, U3.93, U3.94, U3.95, U3.96, U3.97, U3.98, U3.99, U3.100, U3.101, U3.102, VIN1.2
GND2: 3V2.2, BT5.-, BT6.-, C19.2, C20.2, C21.-, C22.2, C23.2, C24.2, C25.2, C26.2, C27.2, D29.A, D32.2, D39.1, E3.GND@0, E3.GND@1, E3.GND@2, E3.GND@3, GEOF2.1, H11.1, J19.GND, J19.GND2, J20.1, J20.7, J20.33, J20.36, J20.39, J20.45, J20.75, J21.GND, J21.GND2, J22.GND@0, J22.GND@1, J22.GND@2, J22.GND@3, J23.1, J24.1, J25.10, J26.3, J26.5, J26.9, J27.1, J27.6, PPS2.1, R43.1, R44.1, R46.1, R51.1, R52.1, R63.1, RTK2.1, S5.1, S5.2, S6.1, S6.2, SPI2.2, U4.4, U4.EP, U6.1, U6.3, U6.12, U6.14, U6.32, U6.37, U6.41, U6.48, U6.55, U6.56, U6.57, U6.58, U6.59, U6.60, U6.61, U6.62, U6.63, U6.64, U6.65, U6.66, U6.67, U6.68, U6.69, U6.70, U6.71, U6.72, U6.73, U6.74, U6.75, U6.76, U6.77, U6.78, U6.79, U6.80, U6.81, U6.82, U6.83, U6.84, U6.85, U6.86, U6.87, U6.88, U6.89, U6.90, U6.91, U6.92, U6.93, U6.94, U6.95, U6.96, U6.97, U6.98, U6.99, U6.100, U6.101, U6.102, VIN2.2
GND3: 3V4.2, BT7.-, BT8.-, C28.2, C29.2, C30.-, C31.2, C32.2, C33.2, C34.2, C35.2, C36.2, D42.A, D45.2, D52.1, E4.GND@0, E4.GND@1, E4.GND@2, E4.GND@3, GEOF3.1, H16.1, J28.GND, J28.GND2, J29.1, J29.7, J29.33, J29.36, J29.39, J29.45, J29.75, J30.GND, J30.GND2, J31.GND@0, J31.GND@1, J31.GND@2, J31.GND@3, J32.1, J33.1, J34.10, J35.3, J35.5, J35.9, J36.1, J36.6, PPS3.1, R64.1, R65.1, R67.1, R72.1, R73.1, R84.1, RTK3.1, S7.1, S7.2, S8.1, S8.2, SPI3.2, U7.4, U7.EP, U8.1, U8.3, U8.12, U8.14, U8.32, U8.37, U8.41, U8.48, U8.55, U8.56, U8.57, U8.58, U8.59, U8.60, U8.61, U8.62, U8.63, U8.64, U8.65, U8.66, U8.67, U8.68, U8.69, U8.70, U8.71, U8.72, U8.73, U8.74, U8.75, U8.76, U8.77, U8.78, U8.79, U8.80, U8.81, U8.82, U8.83, U8.84, U8.85, U8.86, U8.87, U8.88, U8.89, U8.90, U8.91, U8.92, U8.93, U8.94, U8.95, U8.96, U8.97, U8.98, U8.99, U8.100, U8.101, U8.102, VIN3.2
INT: J6.16, J10.2, R11.P8
INT1: J11.16, J16.2, R32.P8
INT2: J20.16, J25.2, R53.P8
INT3: J29.16, J34.2, R74.P8
unnamed: D2.C, R1.2
unnamed: R4.1, VIN.1
unnamed: 3V3.1, R1.1
unnamed: D3.C, R4.2
unnamed: EN.2, J6.4
unnamed: J3.A5, R6.2
unnamed: J3.B5, R7.2
unnamed: R20.1, RTK.2
unnamed: D4.6, R16.1
unnamed: J1.A5, R2.2
unnamed: J1.B5, R3.2
unnamed: D4.3, J3.A6, J3.B6
unnamed: D4.1, J3.A7, J3.B7
unnamed: BT1.+, D6.A, R8.1
unnamed: R11.P1, U1.51
unnamed: R11.P2, U1.50
unnamed: D4.4, R15.1
unnamed: C8.1, FB1.2, R17.1
unnamed: R11.P3, U1.49
unnamed: R11.P4, U1.46
unnamed: R12.P1, U1.45
unnamed: R12.P2, U1.44
unnamed: R12.P3, U1.43
unnamed: R12.P4, U1.42
unnamed: R13.P1, U1.27
unnamed: R13.P2, U1.26
unnamed: PPS.2, R19.1
unnamed: D8.C, R19.2
unnamed: D9.C, R20.2
unnamed: J2.A5, R14.2
unnamed: J2.B5, R18.2
unnamed: D11.C, R24.2
unnamed: BT3.+, D14.A, R23.1
unnamed: EN1.2, J11.4
unnamed: J12.A5, R30.2
unnamed: J12.B5, R31.2
unnamed: D19.3, J12.A6, J12.B6
unnamed: D19.1, J12.A7, J12.B7
unnamed: R34.P1, U3.27
unnamed: R34.P2, U3.26
unnamed: C16.1, FB2.2, R37.1
unnamed: R39.1, RTK1.2
unnamed: PPS1.2, R38.1
unnamed: D20.C, R38.2
unnamed: GEOF.2, R21.1
unnamed: D10.C, R21.2
unnamed: D21.C, R39.2
unnamed: GEOF1.2, R40.1
unnamed: D22.C, R40.2
unnamed: D23.C, R41.2
unnamed: D17.C, R28.2
unnamed: 3V1.1, R28.1
unnamed: R29.1, VIN1.1
unnamed: D18.C, R29.2
unnamed: R33.P1, U3.45
unnamed: R33.P2, U3.44
unnamed: R33.P3, U3.43
unnamed: R33.P4, U3.42
unnamed: R32.P1, U3.51
unnamed: R32.P2, U3.50
unnamed: R32.P3, U3.49
unnamed: R32.P4, U3.46
unnamed: D19.6, R36.1
unnamed: D19.4, R35.1
unnamed: J19.A5, R43.2
unnamed: J19.B5, R44.2
unnamed: BT5.+, D27.A, R45.1
unnamed: EN2.2, J20.4
unnamed: J21.A5, R51.2
unnamed: J21.B5, R52.2
unnamed: D32.3, J21.A6, J21.B6
unnamed: D32.1, J21.A7, J21.B7
unnamed: R55.P1, U6.27
unnamed: R55.P2, U6.26
unnamed: C25.1, FB3.2, R58.1
unnamed: R60.1, RTK2.2
unnamed: PPS2.2, R59.1
unnamed: D33.C, R59.2
unnamed: D34.C, R60.2
unnamed: GEOF2.2, R61.1
unnamed: D35.C, R61.2
unnamed: D36.C, R62.2
unnamed: D30.C, R49.2
unnamed: 3V2.1, R49.1
unnamed: R50.1, VIN2.1
unnamed: D31.C, R50.2
unnamed: R54.P1, U6.45
unnamed: R54.P2, U6.44
unnamed: R54.P3, U6.43
unnamed: R54.P4, U6.42
unnamed: R53.P1, U6.51
unnamed: R53.P2, U6.50
unnamed: R53.P3, U6.49
unnamed: R53.P4, U6.46
unnamed: D32.6, R57.1
unnamed: D32.4, R56.1
unnamed: J28.A5, R64.2
unnamed: J28.B5, R65.2
unnamed: BT7.+, D40.A, R66.1
unnamed: EN3.2, J29.4
unnamed: J30.A5, R72.2
unnamed: J30.B5, R73.2
unnamed: D45.3, J30.A6, J30.B6
unnamed: D45.1, J30.A7, J30.B7
unnamed: R76.P1, U8.27
unnamed: R76.P2, U8.26
unnamed: C34.1, FB4.2, R79.1
unnamed: R81.1, RTK3.2
unnamed: PPS3.2, R80.1
unnamed: D46.C, R80.2
unnamed: D47.C, R81.2
unnamed: GEOF3.2, R82.1
unnamed: D48.C, R82.2
unnamed: D49.C, R83.2
unnamed: D43.C, R70.2
unnamed: 3V4.1, R70.1
unnamed: R71.1, VIN3.1
unnamed: D44.C, R71.2
unnamed: R75.P1, U8.45
unnamed: R75.P2, U8.44
unnamed: R75.P3, U8.43
unnamed: R75.P4, U8.42
unnamed: R74.P1, U8.51
unnamed: R74.P2, U8.50
unnamed: R74.P3, U8.49
unnamed: R74.P4, U8.46
unnamed: D45.6, R78.1
unnamed: D45.4, R77.1
OUT_MEAS: MEAS.1, MEAS.3, U5.1
OUT_MEAS1: MEAS1.1, MEAS1.3, U2.1
OUT_MEAS2: MEAS2.1, MEAS2.3, U4.1
OUT_MEAS3: MEAS3.1, MEAS3.3, U7.1
PPS: D8.A, E1.SIG, J10.1, U1.53
PPS1: D20.A, E2.SIG, J16.1, U3.53
PPS2: D33.A, E3.SIG, J25.1, U6.53
PPS3: D46.A, E4.SIG, J34.1, U8.53
RF_IN: D13.2, FB1.1, J4.SIG, U1.2
RF_IN1: D26.2, FB2.1, J13.SIG, U3.2
RF_IN2: D39.2, FB3.1, J22.SIG, U6.2
RF_IN3: D52.2, FB4.1, J31.SIG, U8.2
RTC_3V: D6.C, D7.C, J6.72, R8.2, TP1.1
RTC_3V1: D14.C, D15.C, J11.72, R23.2, TP4.1
RTC_3V2: D27.C, D28.C, J20.72, R45.2, TP7.1
RTC_3V3: D40.C, D41.C, J29.72, R66.2, TP10.1
RTK_STAT: D9.A, U1.20
RTK_STAT1: D21.A, U3.20
RTK_STAT2: D34.A, U6.20
RTK_STAT3: D47.A, U8.20
RXI1: J11.22, J15.4, R34.P7
RXI2: J6.22, J9.4, R13.P7
RXI3: J20.22, J24.4, R55.P7
RXI4: J29.22, J33.4, R76.P7
RXI/SDI: J6.17, J6.59, J10.11, R12.P6
RXI/SDI1: J11.17, J11.59, J16.11, R33.P6
RXI/SDI2: J20.17, J20.59, J25.11, R54.P6
RXI/SDI3: J29.17, J29.59, J34.11, R75.P6
SCL/SCK: J5.4, J6.14, J6.57, J10.7, R12.P8
SCL/SCK1: J11.14, J11.57, J14.4, J16.7, R33.P8
SCL/SCK2: J20.14, J20.57, J23.4, J25.7, R54.P8
SCL/SCK3: J29.14, J29.57, J32.4, J34.7, R75.P8
SDA/!CS!: J5.3, J6.12, J6.55, J10.8, R12.P7
SDA/!CS!1: J11.12, J11.55, J14.3, J16.8, R33.P7
SDA/!CS!2: J20.12, J20.55, J23.3, J25.8, R54.P7
SDA/!CS!3: J29.12, J29.55, J32.3, J34.8, R75.P7
SWDCK: J6.21, J8.4
SWDCK1: J11.21, J17.4
SWDCK2: J20.21, J26.4
SWDCK3: J29.21, J35.4
SWDIO: J6.23, J8.2, TP2.1
SWDIO1: J11.23, J17.2, TP5.1
SWDIO2: J20.23, J26.2, TP8.1
SWDIO3: J29.23, J35.2, TP11.1
TXO1: J11.20, J15.5, R34.P8
TXO2: J6.20, J9.5, R13.P8
TXO3: J20.20, J24.5, R55.P8
TXO4: J29.20, J33.5, R76.P8
TXO/SDO: J6.19, J6.61, J10.12, R12.P5
TXO/SDO1: J11.19, J11.61, J16.12, R33.P5
TXO/SDO2: J20.19, J20.61, J25.12, R54.P5
TXO/SDO3: J29.19, J29.61, J34.12, R75.P5
TX_READY: J6.10, J10.5, R11.P5
TX_READY1: J11.10, J16.5, R32.P5
TX_READY2: J20.10, J25.5, R53.P5
TX_READY3: J29.10, J34.5, R74.P5
USB_N: J1.A7, J1.B7, J6.5
USB_N1: J2.A7, J2.B7, J11.5
USB_N2: J19.A7, J19.B7, J20.5
USB_N3: J28.A7, J28.B7, J29.5
USB_P: J1.A6, J1.B6, J6.3
USB_P1: J2.A6, J2.B6, J11.3
USB_P2: J19.A6, J19.B6, J20.3
USB_P3: J28.A6, J28.B6, J29.3
VIN: BYP.2, C1.1, C2.+, C13.1, D3.A, F2.2, J6.9, R5.2, R10.2, U5.8
VIN1: BYP1.2, C9.1, C10.1, C11.+, D18.A, F1.2, J11.9, R26.2, R27.2, U2.8
VIN2: BYP2.2, C19.1, C20.1, C21.+, D31.A, F3.2, J20.9, R47.2, R48.2, U4.8
VIN3: BYP3.2, C28.1, C29.1, C30.+, D44.A, F4.2, J29.9, R68.2, R69.2, U7.8
VIN/1: J11.49, R25.2, R26.1
VIN/2: J20.49, R46.2, R47.1
VIN/3: J6.49, R9.2, R10.1
VIN/4: J29.49, R67.2, R68.1
V_BATT: BT2.+, R24.1, TP3.1, U1.36
V_BATT1: BT4.+, R41.1, TP6.1, U3.36
V_BATT2: BT6.+, R62.1, TP9.1, U6.36
V_BATT3: BT8.+, R83.1, TP12.1, U8.36
V_FUSE: BYP.1, D5.C, D12.C, F2.1
V_FUSE1: BYP1.1, D24.C, D25.C, F1.1
V_FUSE2: BYP2.1, D37.C, D38.C, F3.1
V_FUSE3: BYP3.1, D50.C, D51.C, F4.1
V_RF: R17.2, U1.7
V_RF1: R37.2, U3.7
V_RF2: R58.2, U6.7
V_RF3: R79.2, U8.7
V_USB: D5.A, J1.VBUS1, J1.VBUS2
V_USB1: D24.A, J2.VBUS1, J2.VBUS2
V_USB2: D37.A, J19.VBUS1, J19.VBUS2
V_USB3: D50.A, J28.VBUS1, J28.VBUS2
V_USB_1: D19.5, D25.A, J12.VBUS1, J12.VBUS2, J16.6
V_USB_2: D4.5, D12.A, J3.VBUS1, J3.VBUS2, J10.6
V_USB_3: D32.5, D38.A, J21.VBUS1, J21.VBUS2, J25.6
V_USB_4: D45.5, D51.A, J30.VBUS1, J30.VBUS2, J34.6
ZED_USB_N: R16.2, U1.39
ZED_USB_N1: R36.2, U3.39
ZED_USB_N2: R57.2, U6.39
ZED_USB_N3: R78.2, U8.39
ZED_USB_P: R15.2, U1.40
ZED_USB_P1: R35.2, U3.40
ZED_USB_P2: R56.2, U6.40
ZED_USB_P3: R77.2, U8.40

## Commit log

2020-11-06 Initial commit - power M.2 connector
    [F9P_Carrier_Board.brd, F9P_Carrier_Board.sch]
2020-11-06 Adds the F9R and the ESD protection diode
    [F9P_Carrier_Board.brd, F9P_Carrier_Board.sch]
2020-11-20 Mostly finishes schematic
    [F9P_Carrier_Board.brd, F9P_Carrier_Board.sch]
2020-11-20 Puts parts generally where they will be routed
    [F9P_Carrier_Board.brd, F9P_Carrier_Board.sch]
2020-11-23 Still situating the parts within the board
    [F9P_Carrier_Board.brd, F9P_Carrier_Board.sch]
2020-11-23 Moves parts to their final resting places (mostly)
    [F9P_Carrier_Board.brd, F9P_Carrier_Board.sch]
2020-11-30 Routes more air wires - almost done
    [F9P_Carrier_Board.brd, F9P_Carrier_Board.sch]
2020-12-01 Finishes initial routing
    [F9P_Carrier_Board.brd, F9P_Carrier_Board.sch]
2020-12-01 Adds more vias to the design
    [F9P_Carrier_Board.brd]
2020-12-01 Adds even more vias
    [F9P_Carrier_Board.brd]
2020-12-03 Adds silk and measures
    [F9P_Carrier_Board.brd, F9P_Carrier_Board.sch]
2020-12-07 Fixes nets on the ZED-F9P, fixes silk, removes excessive GND vias, adds SMA connector for PPS
    * Fixes 12 pin header
    * Fixes jumper labels in schematic
    * Fixes RX/TX lines, and SDO/SDI lines
    * Adds version number
    [F9P_Carrier_Board.brd, F9P_Carrier_Board.sch]
2020-12-09 Fixes silk, updates schematic with better labels and descriptions
    [F9P_Carrier_Board.brd, F9P_Carrier_Board.sch]
2020-12-09 Removes "INT" trace to MicroMod connector
    [F9P_Carrier_Board.brd, F9P_Carrier_Board.sch]
2020-12-11 Adds micromod silk to the board, fixes zed reset silk
    [F9P_Carrier_Board.brd]
2020-12-11 Adds repo template, cams design for order
    [F9P_Carrier_Board.GBL, F9P_Carrier_Board.GBO, F9P_Carrier_Board.GBP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]
2020-12-14 Updates nets on the 100k at VREG, adds descpription of SPI jumper, adds VBAT testpoint
    [F9P_Carrier_Board.brd, F9P_Carrier_Board.sch]
2021-01-07 Renames the erroneously named SCL/CLK net to SCLK/SCK
    * Reroutes so that SCL and SCK are connected
    [F9P_Carrier_Board.brd, F9P_Carrier_Board.sch]
2021-01-13 Rolls version to v10, moves some vias, deletes I2C_INT net (not used)
    [F9P_Carrier_Board.brd, F9P_Carrier_Board.sch]
2021-01-13 Adjusts battery placement on board so that it's mostly out of the way
    * Breaks out a few general purpose pins to a 6 pin header at the bottom of the board
    * Adds text to led and enable jumpers
    * Adds text about interrupt
    * Adds connection from interrupt on ublox module to micromod connector.
    * Fixes "processor" silk
    [F9P_Carrier_Board.brd, F9P_Carrier_Board.sch]
2021-01-14 Adds I2C address to schematic, swaps SMA connector to female version
    [F9P_Carrier_Board.brd, F9P_Carrier_Board.sch]
2021-01-14 Adds production files - 2x2 panel
    [F9P_Carrier_Board-Panel.GBL, F9P_Carrier_Board-Panel.GBO, F9P_Carrier_Board-Panel.GBP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]
2021-01-15 Removes GPS silk, adds GNSS silk, repanelizes with new silk
    [F9P_Carrier_Board-Panel.GBL, F9P_Carrier_Board-Panel.GBO, F9P_Carrier_Board-Panel.GBS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]
2021-09-14 Adds diode protection to antenna
    [F9P_Carrier_Board.brd, F9P_Carrier_Board.sch]
2021-09-15 Updates silk, moves 1x6 header to the left .005"
    [F9P_Carrier_Board.brd, F9P_Carrier_Board.sch]
2021-09-16 Replaces SMD SMA connector with PTH one
    [F9P_Carrier_Board.brd, F9P_Carrier_Board.sch]
2021-09-16 Updated panel
    [F9P_Carrier_Board-Panel.GBL, F9P_Carrier_Board-Panel.GBO, F9P_Carrier_Board-Panel.GBS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]

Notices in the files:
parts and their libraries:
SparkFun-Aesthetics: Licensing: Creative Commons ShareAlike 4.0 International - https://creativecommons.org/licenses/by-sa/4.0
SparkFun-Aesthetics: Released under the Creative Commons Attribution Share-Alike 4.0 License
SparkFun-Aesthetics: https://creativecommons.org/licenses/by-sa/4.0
